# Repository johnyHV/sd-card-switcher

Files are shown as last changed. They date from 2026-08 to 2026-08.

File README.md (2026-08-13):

# SD Card Switcher

A simple hardware device for switching a microSD card between a PC and another SD-card host device. 

<div align="center">
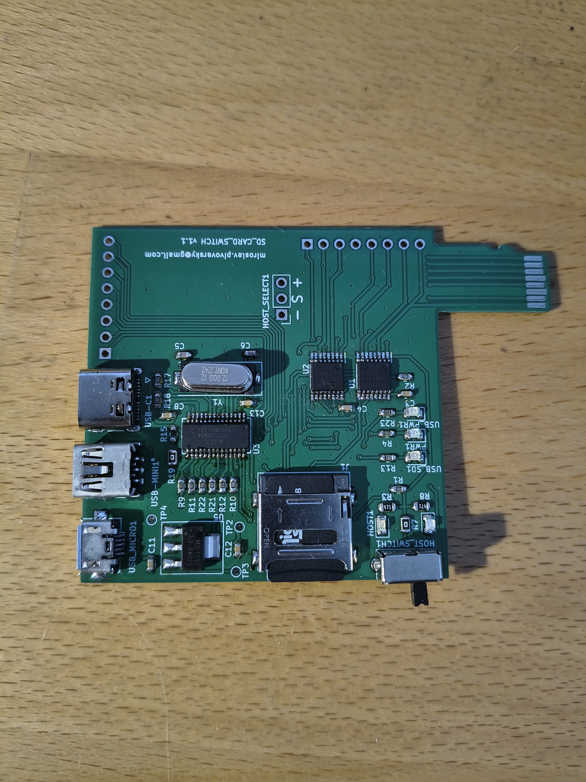
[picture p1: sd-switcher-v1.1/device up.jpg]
  
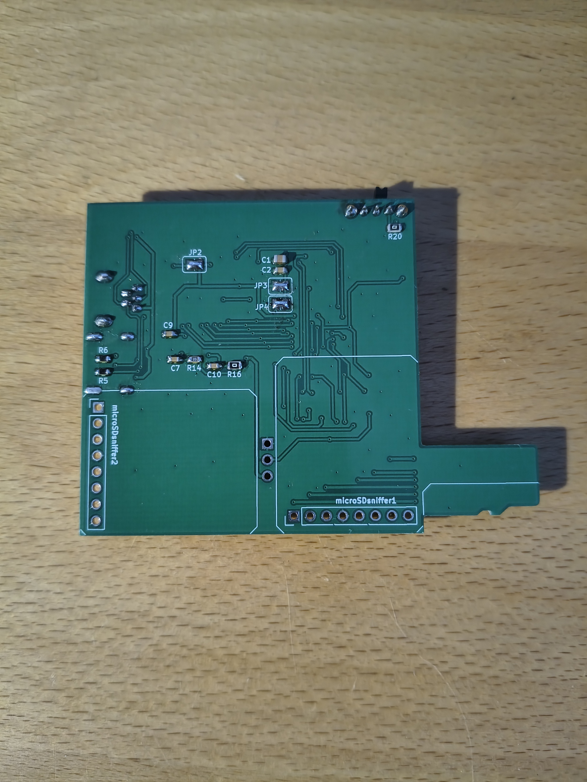
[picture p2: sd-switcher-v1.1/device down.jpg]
  
</div>

## Use Cases

Useful for devices where an SD card needs to be frequently accessed from both the target device and a PC, for example:

- Firmware development and testing
- Embedded Linux development
- 3D printers
- Single-board computers
- SD-card based embedded devices
- Easy access to logs and configuration files

The switch changes the physical connection of the SD card; it does not copy or synchronize data.

## How it works

The device contains:

* USB interface for connecting the card to a PC
* microSD card slot
* SD-card-shaped PCB with an SD edge connector
* Hardware switch for selecting the active connection

Insert a microSD card into the onboard slot and plug the SD-shaped PCB into the target device.

The switch selects whether the microSD card is connected to:

* **PC** via USB
* **Target device** via the SD card interface

This allows the same SD card to be easily switched between a computer and the target device without physically removing the card.

## Main Components

| Component | Part |
| --- | --- |
| USB/SD card controller | GL827 |
| Bus switch | SN74CBT3257D |
| SD card socket | 693072010801 |
| USB-C connector | Molex 105450-0101 |
| Micro USB connector | Molex 54819-0519 |
| Switch | SPDT switch |
| LED | LED |
| Passives | Resistors and capacitors |

## Schematic

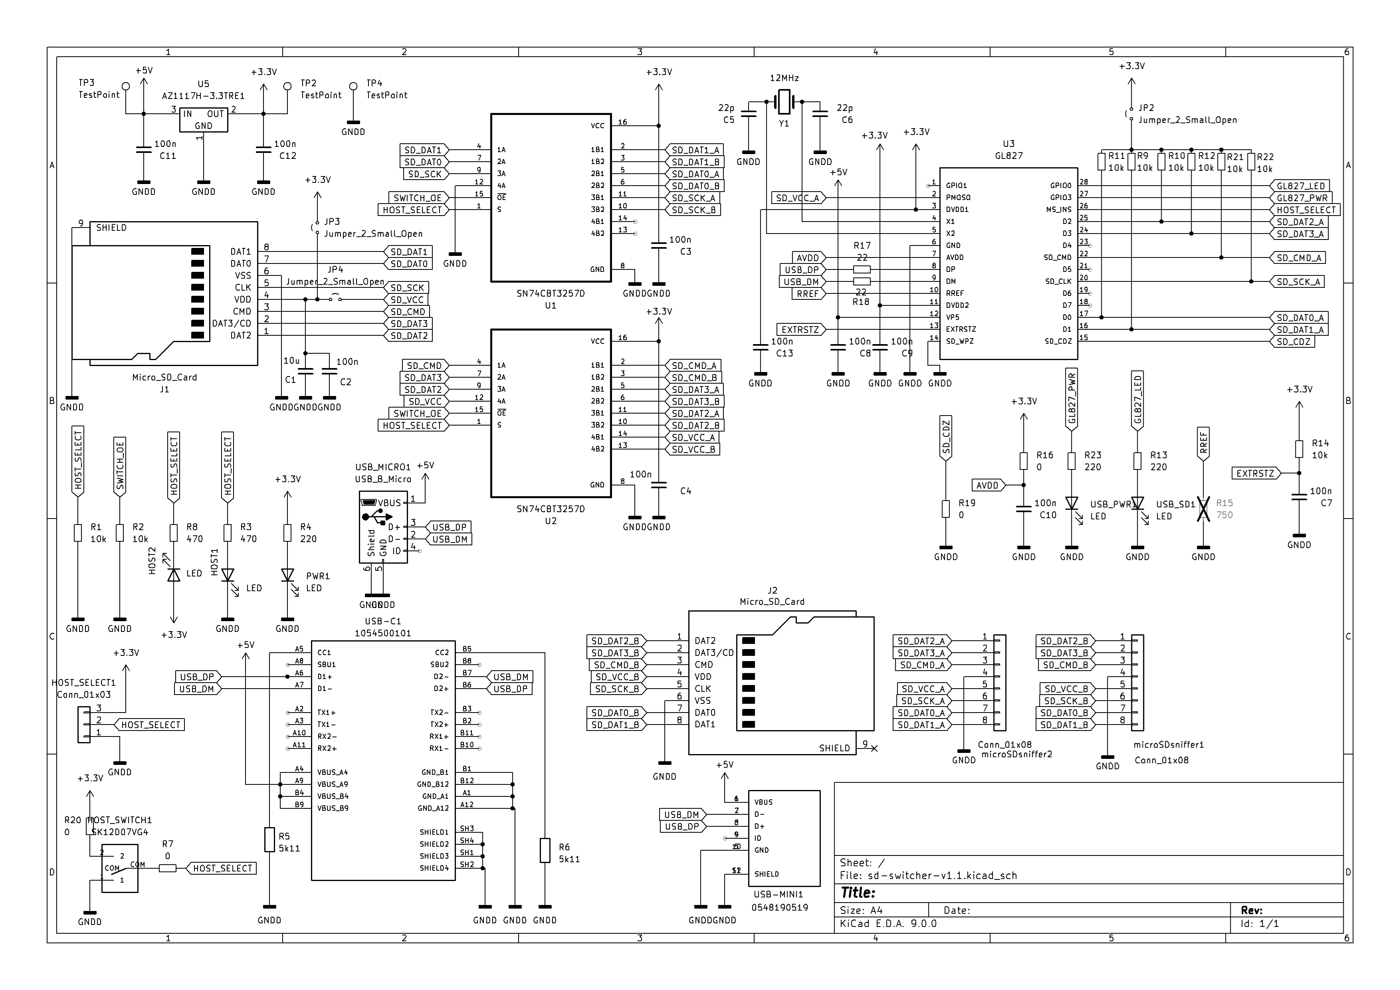
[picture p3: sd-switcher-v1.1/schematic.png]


## PCB

**PCB thickness: 0.8 mm**

The SD-shaped PCB edge connector requires a 0.8 mm PCB thickness to fit properly into a standard SD card slot.

The PCB was manufactured by [JLCPCB](https://jlcpcb.com/?from=GRVYI). This is a referral link. 

## Files

This repository contains the PCB design files and manufacturing files required to build the SD Card Switcher.

## Disclaimer

This project is provided "as is", without any warranty.

The author is not responsible for any damage to SD cards, connected devices, computers, or other hardware resulting from the use, modification, or construction of this project.

Build and use it at your own risk.

## License

Open-source hardware project.

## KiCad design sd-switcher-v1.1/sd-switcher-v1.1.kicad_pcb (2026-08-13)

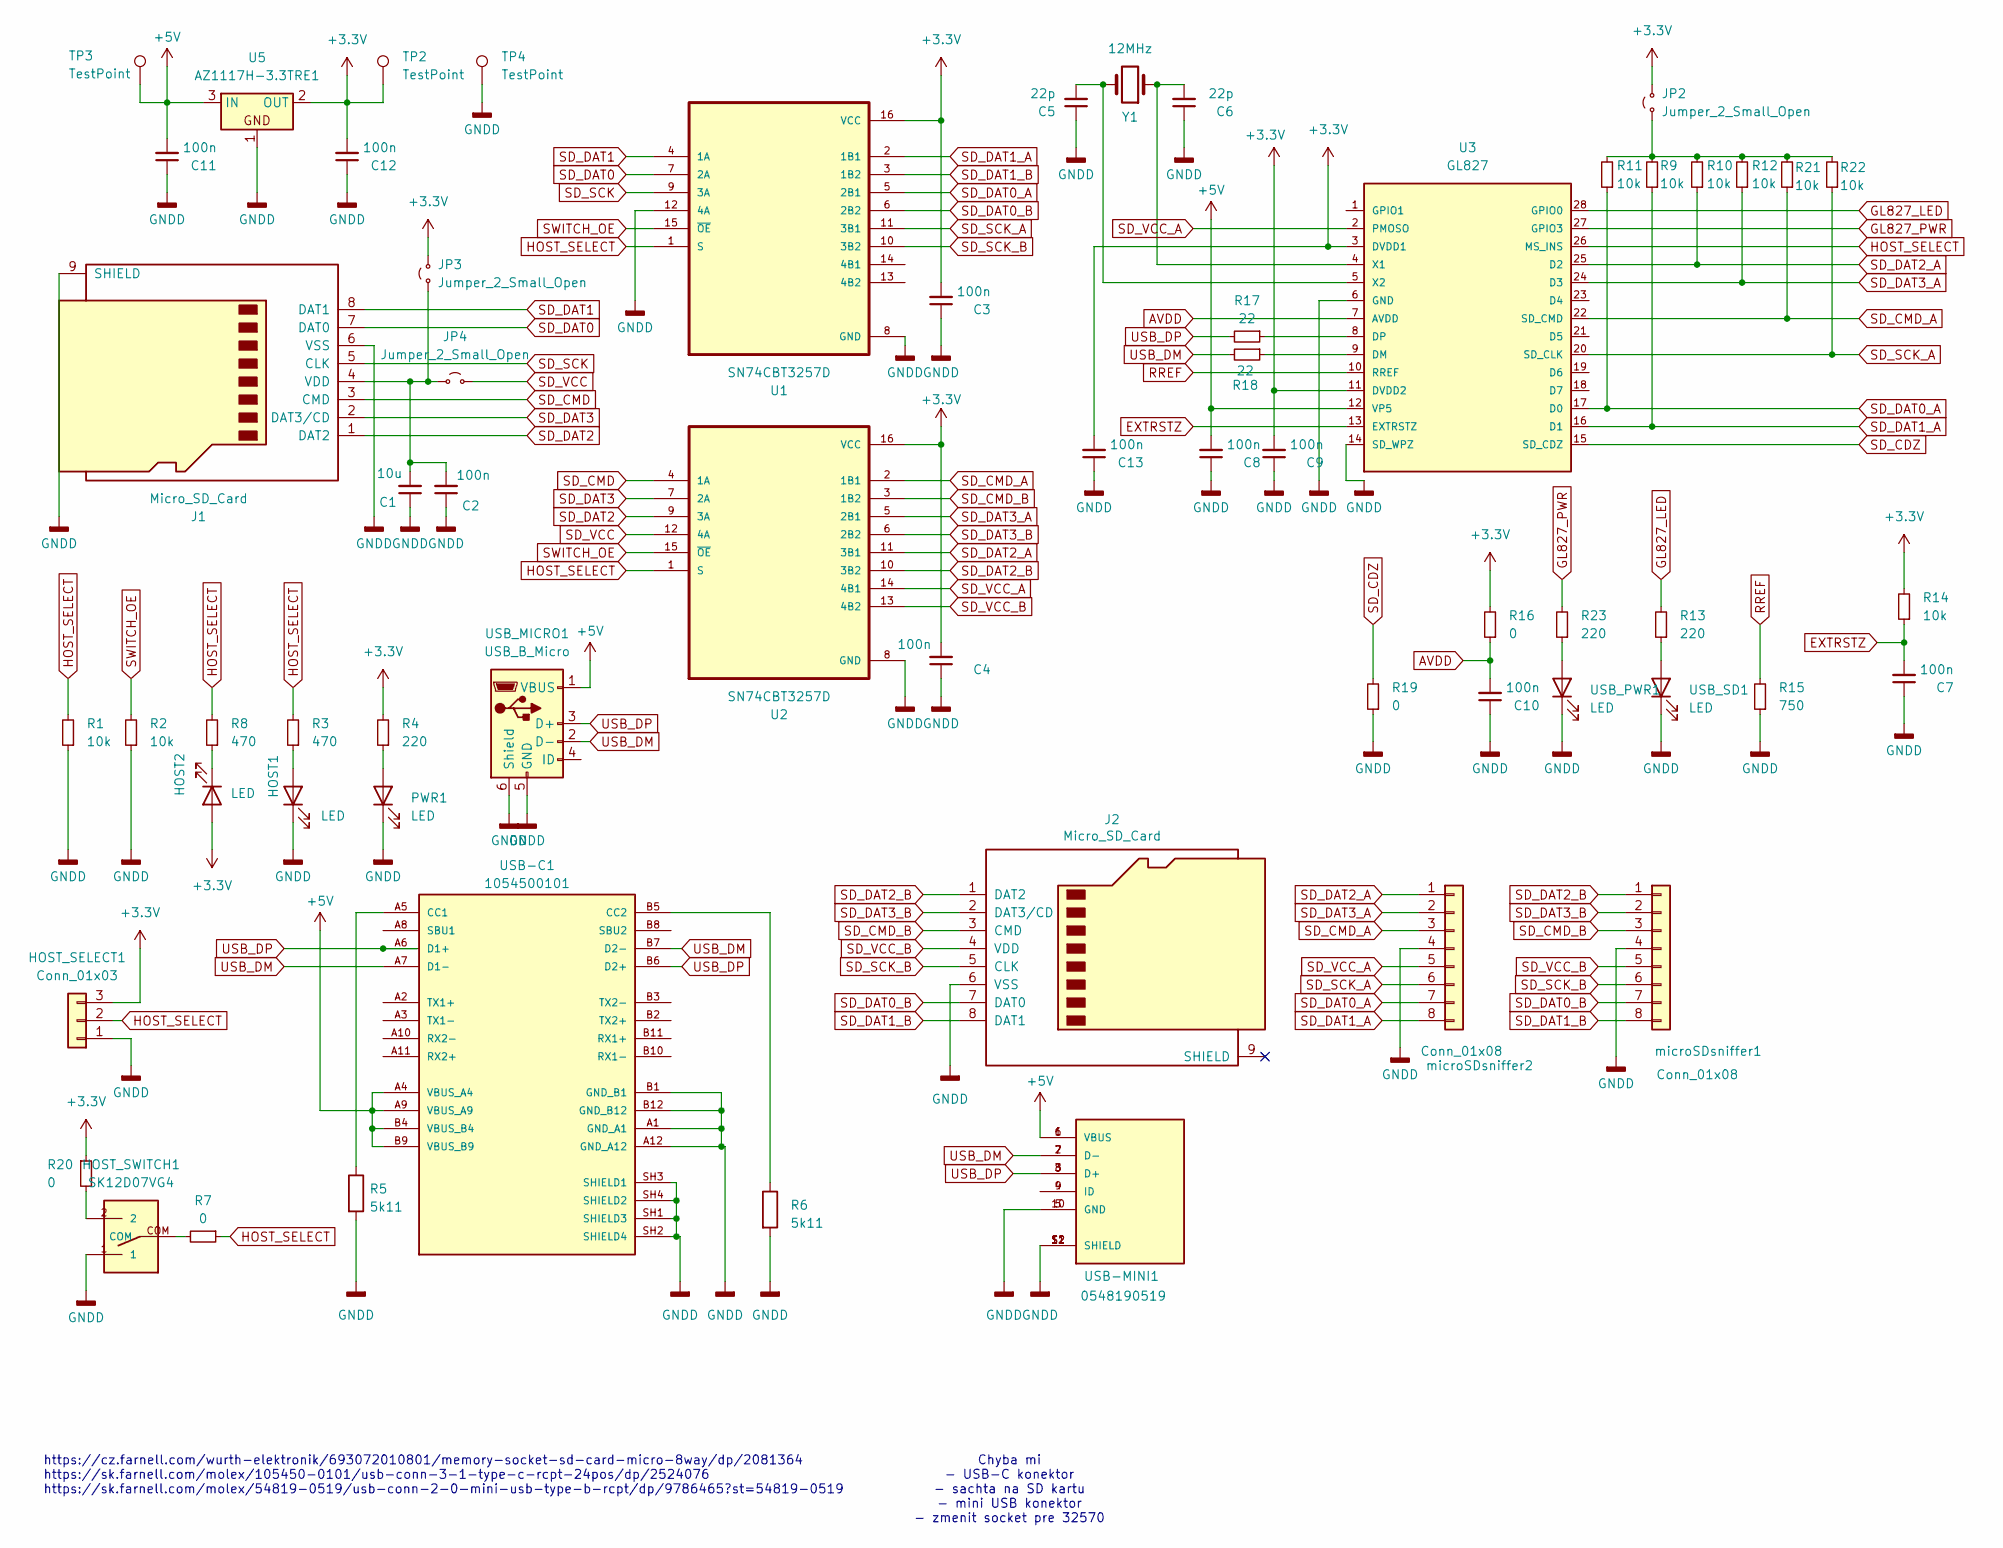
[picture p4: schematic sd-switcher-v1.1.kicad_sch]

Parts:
C1: 10u; C_0603_1608Metric
C2, C3, C4, C7, C8, C9, C10, C11, C12, C13: 100n; C_0603_1608Metric
C5, C6: 22p; C_0603_1608Metric
HOST1, HOST2: LED; LED_0805_2012Metric
HOST_SELECT1: Conn_01x03; PinHeader_1x03_P2.54mm_Vertical; Part Number 1-0301FBV0T
HOST_SWITCH1: SK12D07VG4
J1: Micro_SD_Card; microSD_HC_Wuerth_693072010801
J2: Micro_SD_Card; microSD_card
JP2, JP3, JP4: Jumper_2_Small_Open; JUMPER_SMD_1x2
PWR1: LED; LED_0805_2012Metric
R1, R2, R9, R10, R11, R12, R14, R21, R22: 10k; R_0603_1608Metric
R3, R8: 470; R_0603_1608Metric
R4, R13, R23: 220; R_0603_1608Metric
R5, R6: 5k11; R_0603_1608Metric
R7, R16, R19, R20: 0; R_0603_1608Metric
R15: 750; R_0603_1608Metric
R17, R18: 22; R_0603_1608Metric
TP2, TP3, TP4: TestPoint; TestPoint_Pad_D1.0mm
U1, U2: SN74CBT3257D; SOP65P640X110-16N
U3: GL827; SSOP28
U5: AZ1117H-3.3TRE1; SOT-223-3_TabPin2
USB-C1: 1054500101; MOLEX_1054500101; PARTREV A7
USB-MINI1: 0548190519; MOLEX_0548190519; PARTREV A
USB_MICRO1: USB_B_Micro; USB_Micro-B_Amphenol_10104110_Horizontal
USB_PWR1: LED; LED_0805_2012Metric
USB_SD1: LED; LED_0805_2012Metric
Y1: 12MHz; Crystal_SMD_HC49-SD
microSDsniffer1, microSDsniffer2: Conn_01x08; sparkfun sd sniffer

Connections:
+3.3V: C3.2, C4.2, C9.2, C12.2, C13.2, HOST2.2 (A), HOST_SELECT1.3, JP2.2 (B), JP3.2 (B), R4.2, R14.2, R16.2, R20.1, TP2.1, U1.16 (VCC), U2.16 (VCC), U3.3 (DVDD1), U3.11 (DVDD2), U5.2 (OUT)
+5V: C8.2, C11.2, TP3.1, U3.12 (VP5), U5.3 (IN), USB-C1.A4 (VBUS_A4), USB-C1.A9 (VBUS_A9), USB-C1.B4 (VBUS_B4), USB-C1.B9 (VBUS_B9), USB-MINI1.1 (VBUS), USB-MINI1.6 (VBUS), USB_MICRO1.1 (VBUS)
AVDD: C10.2, R16.1, U3.7 (AVDD)
EXTRSTZ: C7.2, R14.1, U3.13 (EXTRSTZ)
GL827_LED: R13.2, U3.28 (GPIO0)
GL827_PWR: R23.2, U3.27 (GPIO3)
GNDD: C1.1, C2.1, C3.1, C4.1, C5.1, C6.1, C7.1, C8.1, C9.1, C10.1, C11.1, C12.1, C13.1, HOST1.1 (K), HOST_SELECT1.1, HOST_SWITCH1.1, J1.6 (VSS), J1.9 (SHIELD), J2.6 (VSS), PWR1.1 (K), R1.1, R2.1, R5.2, R6.2, R15.1, R19.1, TP4.1, U1.8 (GND), U1.12 (4A), U2.8 (GND), U3.6 (GND), U3.14 (SD_WPZ), U5.1, USB-C1.A1 (GND_A1), USB-C1.A12 (GND_A12), USB-C1.B1 (GND_B1), USB-C1.B12 (GND_B12), USB-C1.SH1 (SHIELD3), USB-C1.SH2 (SHIELD4), USB-C1.SH3 (SHIELD1), USB-C1.SH4 (SHIELD2), USB-MINI1.5 (GND), USB-MINI1.10 (GND), USB-MINI1.11 (SHIELD), USB-MINI1.12 (SHIELD), USB-MINI1.S1 (SHIELD), USB-MINI1.S2 (SHIELD), USB_MICRO1.5 (GND), USB_MICRO1.6 (Shield), USB_PWR1.1 (K), USB_SD1.1 (K), microSDsniffer1.4, microSDsniffer2.4
HOST_SELECT: HOST_SELECT1.2, R1.2, R3.2, R7.1, R8.2, U1.1 (S), U2.1 (S), U3.26 (MS_INS)
unnamed: HOST1.2 (A), R3.1
unnamed: HOST2.1 (K), R8.1
unnamed: HOST_SWITCH1.2, R20.2
unnamed: HOST_SWITCH1.COM, R7.2
unnamed: C1.2, C2.2, J1.4 (VDD), JP3.1 (A), JP4.1 (A)
unnamed: JP2.1 (A), R9.2, R10.2, R11.2, R12.2, R21.2, R22.2
unnamed: PWR1.2 (A), R4.1
unnamed: R18.1, U3.9 (DM)
unnamed: R17.1, U3.8 (DP)
unnamed: C6.2, U3.4 (X1), Y1.1
unnamed: C5.2, U3.5 (X2), Y1.2
unnamed: R5.1, USB-C1.A5 (CC1)
unnamed: R6.1, USB-C1.B5 (CC2)
unnamed: USB-MINI1.4 (ID), USB-MINI1.9 (ID)
unnamed: R23.1, USB_PWR1.2 (A)
unnamed: R13.1, USB_SD1.2 (A)
RREF: R15.2, U3.10 (RREF)
SD_CDZ: R19.2, U3.15 (SD_CDZ)
SD_CMD: J1.3 (CMD), U2.4 (1A)
SD_CMD_A: R21.1, U2.2 (1B1), U3.22 (SD_CMD), microSDsniffer2.3
SD_CMD_B: J2.3 (CMD), U2.3 (1B2), microSDsniffer1.3
SD_DAT0: J1.7 (DAT0), U1.7 (2A)
SD_DAT0_A: R11.1, U1.5 (2B1), U3.17 (D0), microSDsniffer2.7
SD_DAT0_B: J2.7 (DAT0), U1.6 (2B2), microSDsniffer1.7
SD_DAT1: J1.8 (DAT1), U1.4 (1A)
SD_DAT1_A: R9.1, U1.2 (1B1), U3.16 (D1), microSDsniffer2.8
SD_DAT1_B: J2.8 (DAT1), U1.3 (1B2), microSDsniffer1.8
SD_DAT2: J1.1 (DAT2), U2.9 (3A)
SD_DAT2_A: R10.1, U2.11 (3B1), U3.25 (D2), microSDsniffer2.1
SD_DAT2_B: J2.1 (DAT2), U2.10 (3B2), microSDsniffer1.1
SD_DAT3: J1.2 (DAT3/CD), U2.7 (2A)
SD_DAT3_A: R12.1, U2.5 (2B1), U3.24 (D3), microSDsniffer2.2
SD_DAT3_B: J2.2 (DAT3/CD), U2.6 (2B2), microSDsniffer1.2
SD_SCK: J1.5 (CLK), U1.9 (3A)
SD_SCK_A: R22.1, U1.11 (3B1), U3.20 (SD_CLK), microSDsniffer2.6
SD_SCK_B: J2.5 (CLK), U1.10 (3B2), microSDsniffer1.6
SD_VCC: JP4.2 (B), U2.12 (4A)
SD_VCC_A: U2.14 (4B1), U3.2 (PMOSO), microSDsniffer2.5
SD_VCC_B: J2.4 (VDD), U2.13 (4B2), microSDsniffer1.5
SWITCH_OE: R2.2, U1.15 (~OE), U2.15 (~OE)
USB_DM: R18.2, USB-C1.A7 (D1-), USB-C1.B7 (D2-), USB-MINI1.2 (D-), USB-MINI1.7 (D-), USB_MICRO1.2 (D-)
USB_DP: R17.2, USB-C1.A6 (D1+), USB-C1.B6 (D2+), USB-MINI1.3 (D+), USB-MINI1.8 (D+), USB_MICRO1.3 (D+)

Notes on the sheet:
https://cz.farnell.com/wurth-elektronik/693072010801/memory-socket-sd-card-micro-8way/dp/2081364 https://sk.farnell.com/molex/105450-0101/usb-conn-3-1-type-c-rcpt-24pos/dp/2524076 https://sk.farnell.com/molex/54819-0519/usb-conn-2-0-mini-usb-type-b-rcpt/dp/9786465?st=54819-0519
Chyba mi - USB-C konektor - sachta na SD kartu - mini USB konektor - zmenit socket pre 32570

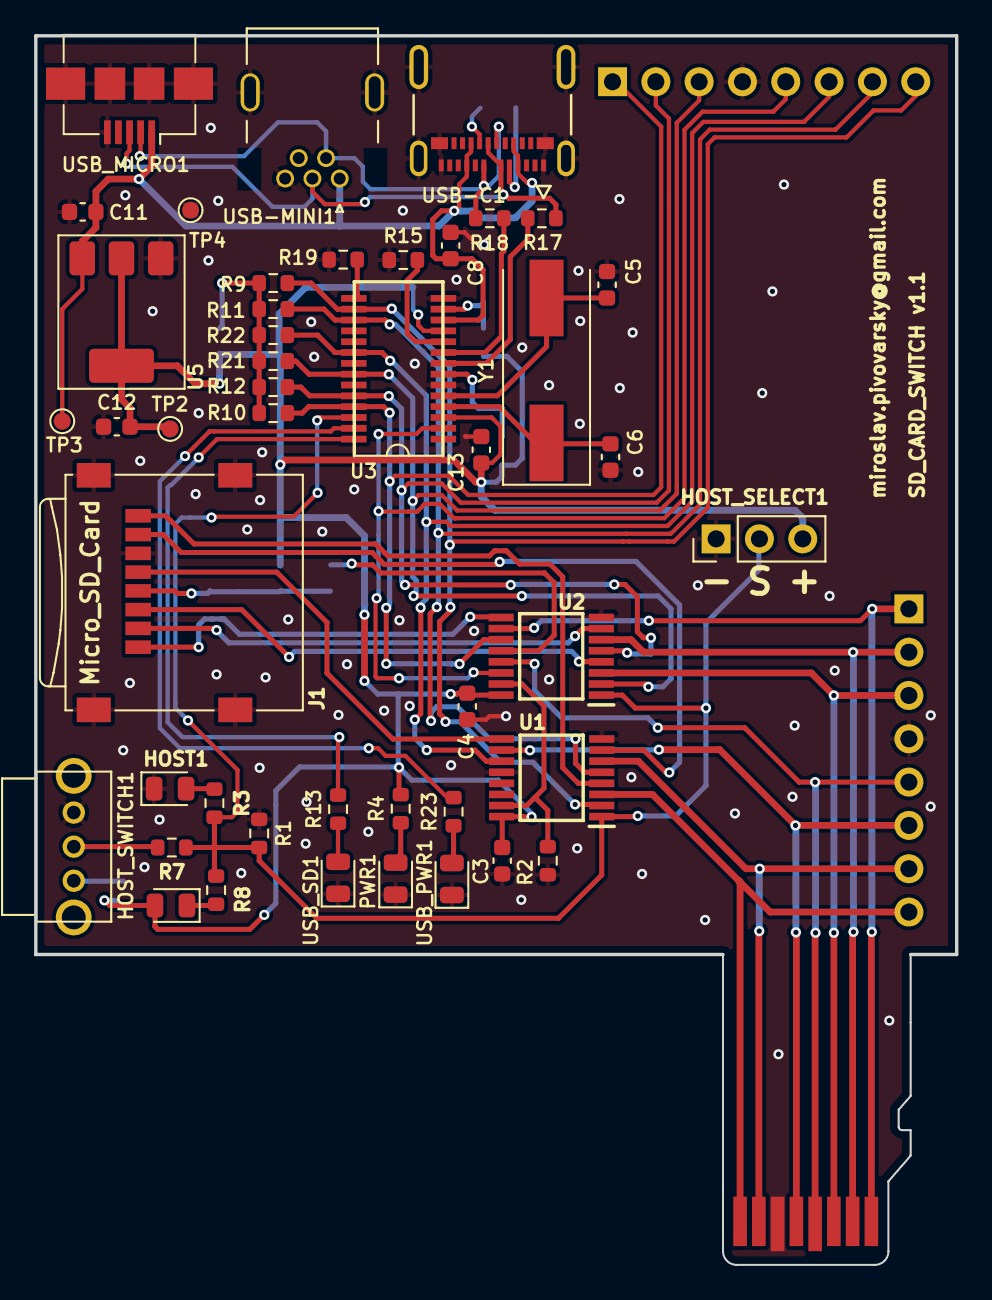
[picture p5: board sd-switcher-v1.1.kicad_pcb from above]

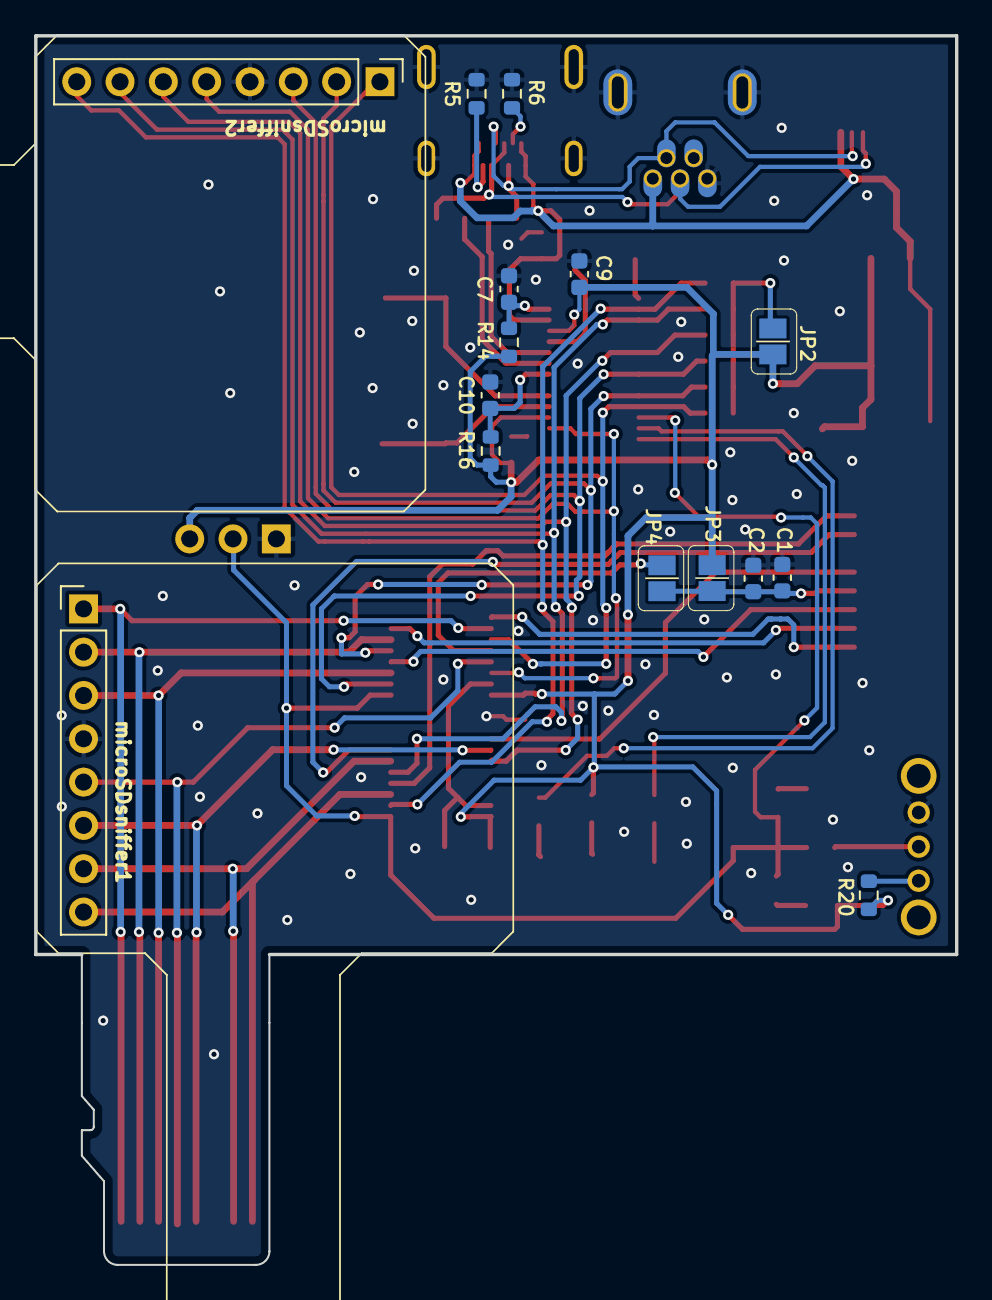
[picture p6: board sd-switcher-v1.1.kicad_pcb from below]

Board: 2 copper layers, 54.0 x 72.1 mm, 61 parts (15 on the bottom side), 50 nets.

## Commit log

2026-08-13 Added schematic and PCB
    [sd-switcher-v1.1.kicad_pcb, sd-switcher-v1.1.kicad_sch]
2026-08-13 added kicad lib
2026-08-13 added manufacter gerbera data
2026-08-13 added schematic png
